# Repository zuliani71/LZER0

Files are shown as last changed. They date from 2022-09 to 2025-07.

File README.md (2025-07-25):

# LZER0


LZER0: a cost-effective multi-purpose GNSS platform (Hardware and Software) developed by OGS for surveying measurements and for monitoring tasks.

## 🔍 Overview
- 📇 Based on u‑blox GNSS receivers (M8T and ZED F9P) + Raspberry Pi Zero W.
- 🧰 Processes data with RTKLIB (real-time RTK/PPK).
- 🖥️ Includes Bash scripts, Ansible provisioning, and web interface for fleet management

## 🚀 Getting Started

To fully utilize an LZER0 device, you will need to set up the hardware, deploy and configure the device's operating system and software, and optionally integrate it into a centralized management system.

### Choose Your Path
- 🔧 **I want to build the hardware** → Continue to the [Hardware Guide](#%EF%B8%8F-hardware-guide) section below
- 💻 **I want to deploy and configure devices** → Go to the [LZER0 Deployment and Provisioning](https://hub.geosciences.cloud/git/geosciencesir-devop/ogs_dev/lzer0_provisioning) repository
- 🌐 **I want to set up the web-based centralized management and configuration system** → Check out the [GNSS-Central-Config](https://hub.geosciences-ir.it/git/geosciencesir-devop/ogs_dev/gnss-central-config) system
- 🛠️ **I want to use command-line tools to interact with LZER0 devices** → Explore the [lzeroutils repository](https://github.com/shakelab/lzeroutils)
- 📚 **I want to understand the complete system** → Continue reading this guide and explore the [research publications](#-articles-and-informations-available-at)

### LZER0 Deployment and Provisioning
The LZER0 Deployment and Provisioning repository is crucial for bringing new Raspberry Pi units to an operative state, allowing them to join a pool of already deployed boards. This process involves a combination of ad-hoc OS image building using pi-gen and IT automation with Ansible.

**Key Stages:**
- **Image Building Stage:** Utilizes pi-gen to create a Raspberry Pi OS Lite image, which is then written to the SD cards of the RPis. This stage includes custom scripts (90-crspi) for installing extra packages, disabling unneeded hardware/services, setting up NetworkManager, and populating a custom.toml file for first-boot scripts.

  - **Customization:** Before the first boot, you can apply board-specific customizations to the SD card, such as setting a custom hostname and providing client-specific VPN configurations.

- **Provisioning Stage:** Uses Ansible playbooks to define and run tasks on all hosts in the inventory.

  - **Inventory Population:** The Ansible inventory can be populated manually or dynamically using Avahi for discovery of IP addresses and hostnames.

  - **Playbooks:** A comprehensive set of Ansible playbooks (main.yaml) is provided for tasks like disabling requiretty, configuring fstab, installing/updating apt packages, managing user groups and SSH keys, setting up NTP, configuring the ufw firewall, establishing persistent VPN connections, syncing root and home directories, installing Python packages with pip, deploying RTKLIB, setting up the GNSS module web interface, configuring PiJuice, and managing crontab entries.

For detailed instructions, please refer to the `README.md` in the [LZER0 Deployment and Provisioning](https://hub.geosciences.cloud/git/geosciencesir-devop/ogs_dev/lzer0_provisioning) repository.

### GNSS-Central-Config

The [GNSS-Central-Config](https://hub.geosciences-ir.it/git/geosciencesir-devop/ogs_dev/gnss-central-config) system enables centralized management of a pool of LZER0 receivers. This system facilitates defining and distributing device configurations, monitoring their status, updating parameters, and coordinating the behavior of the entire GNSS network. This is particularly useful for fleet management, allowing programmatic updates to keep configuration files in sync across all deployed boards.

In addition to the central system, each receiver also hosts a local web-based configuration interface. This configurator plays a crucial role, as it allows the setup of key parameters specific to each device — such as site name, caster credentials, approximate coordinates, and more. While the central system ensures coordination and consistency, the local interface ensures that each receiver can be individually tailored to its deployment context.

## 📦 Components

<table>
  <thead>
    <tr>
      <th style="width: 200px;">Repo</th>
      <th>Description</th>
    </tr>
  </thead>
  <tbody>
    <tr>
      <td colspan="2"><strong>🧰 Software</strong></td>
    </tr>
    <tr>
      <td><a href="https://github.com/OGS-GNSS/homebin_lzer0">homebin_lzer0</a></td>
      <td>Contains scripts, tools, and utility software necessary for the daily operation of the LZER0 receiver. It includes tools for starting services, managing GNSS files, communicating with peripherals, and other system operations. It is the central component that defines the behavior of the device once it is powered on.</td>
    </tr>
    <tr>
      <td><a href="https://github.com/OGS-GNSS/homecfg_lzer0">homecfg_lzer0</a></td>
      <td>Contains examples of the configuration file related to the operation of the LZER0 receiver. Some files are used directly, others are dynamically regenerated at provisioning or boot time.</td>
    </tr>
    <tr>
      <td colspan="2"><strong>🌐 Web-based configuration system</strong></td>
    </tr>
    <tr>
      <td><a href="https://hub.geosciences-ir.it/git/geosciencesir-devop/ogs_dev/gnss-central-config">GNSS-Central-Config</a> (soon public)</td>
      <td>Web interface for centralized management of a pool of LZER0 receivers. It allows you to define and distribute device configurations, monitor their status, update parameters, and coordinate the behavior of the entire GNSS network.</td>
    </tr>
    <tr>
      <td colspan="2"><strong>⚙️ Deployment system</strong></td>
    </tr>
    <tr>
      <td><a href="https://hub.geosciences.cloud/git/geosciencesir-devop/ogs_dev/lzer0_provisioning">LZER0 Deployment and Provisioning</a> (soon public)</td>
      <td>Main repository for the automatic deployment and provisioning of lzer0 devices. It manages the entire device lifecycle: from initial power-up to final configuration. Includes scripts for installation, cloning of the required repositories, and network and service setup.</td>
    </tr>
    <tr>
      <td><a href="https://github.com/OGS-GNSS/lzer0_generic_assets">Assets to be configured</a></td>
      <td>Contains the customizable assets needed to adapt the provisioning system to your operating environment. This repository is automatically cloned by the provisioning system.</td>
    </tr>
     <tr>
      <td colspan="2"><strong>🛠️ Client-Server tools </strong></td>
       <tr>
        <td><a href="https://github.com/shakelab/lzeroutils">lzeroutils</a></td>
        <td>Supplementary command-line tools and utilities to interact with LZER0 devices. Useful for debugging, automation, and data extraction. Can be used independently or integrated with the core system.</td>
      </tr>
    </tr>
  </tbody>
</table>

## 🛠️ Hardware Guide

This repository contains all the hardware designs, schematics, and documentation needed to build LZER0 devices.

### What You'll Find Here

#### Core Hardware Designs
- **PCB schematics** - Complete electrical designs for LZER0 boards
- **PCB layouts** - Ready-to-manufacture Gerber files
- **Bill of Materials (BOM)** - Component lists with part numbers
- **Assembly instructions** - Step-by-step hardware assembly guides
- **Mechanical drawings** - Enclosure and mounting specifications

#### Key Components
- **u-blox GNSS receiver module (M8T and ZED F9P)** - Professional-grade timing receiver
- **Raspberry Pi Zero W** - ARM-based computing platform with WiFi
- **Custom interface PCB** - Connects GNSS receiver to Raspberry Pi
- **Power management** - Efficient power supply and distribution
- **I/O interfaces** - GPIO, serial, and expansion connectors

#### Important Note
The original LZER0 hardware was developed using the u-blox M8T receiver. However, this repository also includes designs for the LCC variant, based on the u-blox ZED-F9P, which supports multi-band GNSS and offers enhanced precision and performance.

### Manufacturing Your LZER0

1. **Download design files** from the `/hardware/` directory
2. **Source components** using the provided BOM
3. **Manufacture PCBs** using the Gerber files with your preferred fabricator
4. **Assemble hardware** following the assembly guide
5. **Test hardware** before software installation

### Hardware Variants

LZER0 supports multiple hardware configurations:

#### LZER0-MONI 
Intended for permanent monitoring applications such as landslide or infrastructure observation. The unit is typically installed inside a solar-powered pillar with a panel, charge controller, and backup battery. It features the u-blox M8T receiver and 

Raspberry Pi connected via USB, and includes a built-in web server with real-time data visualization (e.g., NS/EW/UP displacements and interactive map).

#### LZER0-TOPO
A compact version designed for topographic and cadastral surveying. It uses a u-blox M8T GNSS receiver and a rechargeable LiPo battery, all housed in a 3D-printed enclosure with an integrated TW4721 antenna on a metallic support. The device connects wirelessly to an Android tablet, enabling real-time tracking of survey points and trajectories in the field.

#### LZER0-AUTO
Developed for automotive and dynamic positioning applications, such as agricultural machinery. The electronics (u-blox M8T, Raspberry Pi Zero W, and ATXraspi interface board) are enclosed in a rugged industrial-grade Gewiss GW44427 box. Powered by the vehicle's battery (24V to 5V converter), it connects to a tablet in the cabin, which provides NTRIP corrections and real-time guidance

#### LZER0-MOB (documentation will be uploaded)
LZER0-MOB is a standalone GNSS device designed for temporary measurement campaigns and mobile deployments. It integrates a GNSS receiver (u-blox ZED-F9P), a Raspberry Pi, and an internal modem for remote connectivity.
It can be powered by external batteries or solar panels, making it fully autonomous and ideal for rapid field deployment.

Developed within the Geosciences IR project, it uses the LZER0 Core Card (LCC) ver. 2021, based on the u-blox ZED-F9 chipset.

#### LZER0-NET (documentation will be uploaded)
LZER0-NET is built for reliable, continuous GNSS monitoring, especially in remote or critical installations. It includes a mini-UPS based on the PiJuice board, enabling power backup, safe shutdowns, and automatic recovery.

It combines the u-blox ZED-F9 GNSS receiver with a Raspberry Pi and supports real-time data streaming and web-based monitoring.
It features the LZER0 Core Card (LCC) ver. 2022, based on the same ZED-F9 chipset, with improved hardware integration.

## ✨Acknowledgments
The development of LZER0 has been supported over the years by several projects and funding sources:
- the development of the LZER0-NET and of the LCC was supported by the agreement between the National Institute of Oceanography and Applied Geophysics - OGS and the Civil Protection of the Friuli Venezia Giulia Region;
- the development of the LZER0-MOB variant, of the GNSS-Central-Config system and of the LZER0 Deployment and Provisioning system was funded by European Union - NextGenerationEU - Mission 4 “Education and Research” - Component 2 “From Research to Business” - Investment 3.1 “Fund for the realization of an integrated system of research and innovation infrastructures” - Project IR0000037 - GeoSciences IR - CUP I53C22000800006;
- LZER0 was tested within the RETURN project as a real-time monitoring device at the Cazzaso landslide, at two test sites on a building of the University of Naples, and at two sites along the Rome–Naples railway line. As part of the RETURN project, and in collaboration with Sapienza University of Rome, we are also carrying out a technology transfer initiative aimed at increasing the Technology Readiness Level (TRL) of the LZER0 system.

LZER0 software integrates software developed in the following third-party projects:
- [RTKLIB](https://github.com/rtklibexplorer/RTKLIB)
- [Ansible](https://www.ansible.com/)
- [Pi-Gen](https://github.com/RPi-Distro/pi-gen)

## 📄 Articles and informations available at:
- https://doi.org/10.3390/s22218314<br>
- https://doi.org/10.5194/egusphere-egu2020-9506<br>
- http://dx.doi.org/10.13140/RG.2.2.22750.05447<br>
- http://dx.doi.org/10.13140/RG.2.2.32319.61605<br>
- https://doi.org/10.3390/s22010350<br>
- https://hdl.handle.net/20.500.14083/43383<br>

## 📄 License

This project is licensed under the [Creative Commons Attribution 4.0 International (CC BY 4.0)](https://creativecommons.org/licenses/by/4.0/) license.



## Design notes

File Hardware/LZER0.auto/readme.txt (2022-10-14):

This version needs:
a) a rasperry pi zero W
b) an ATXRaspi board available at: https://lowpowerlab.com/guide/atxraspi/
c) an u-blox M8T USB board (see the pdf schematic here included)

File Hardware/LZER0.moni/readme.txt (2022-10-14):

This version needs:
a) a rasperry pi zero W
b) an external power supply system (e.g. solar pannels and batteries)
c) an external data transmission system (e.g. LAN ethernet)
d) an u-blox M8T USB board (see the pdf schematic included in Hardware/LZER0.auto)

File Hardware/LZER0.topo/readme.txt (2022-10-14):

a) a rasperry pi zero W
b) an u-blox M8T OGS board (see the schematic_eagle_4_16 dir)
c) an optional enclosure (see the 3D_sketchup dir)

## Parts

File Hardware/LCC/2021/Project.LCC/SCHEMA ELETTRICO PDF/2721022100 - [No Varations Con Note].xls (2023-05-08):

 | Component list |  |  |  | LZER0 Core Card
 | Project: |  |  |  | 2721022100
 | Variant: |  |  |  | 1.4 [no variant (completa)]
 | Report Date: |  |  | 18/08/2022 | 18:24
 | Print Date: |  |  | 2022-08-23 | 17:52:29
# | Designator | Comment | Case | Manufacturer n | Order c | Description |  |  | Quantity
1 | B1 | 3V |  | MS621FE-FL11E | 628-MS621FE-FL11E | Recharge Battery/Tab RTC/SRAM Backup |  | 0 | 1
2 | C1, C3, C5, C6, C7, C9, C10, C13 | 10uF | 603 | GRM188R61A106ME69D | 81-GRM188R61A106ME9D | CAP, MLCC, X5R, 10UF, 10V, X5R, 0603 | 0.03 | 0.24 | 8
3 | C2, C4, C11 | 100nF | 402 | GRM155R71C104KA88D | 8819742 | CAP, CERAMICA, 100NF, 16V, X7R, 0402 | 0.01 | 0.03 | 3
4 | C8 | 100nF | 603 | GRM188R71H104KA93 | 81-GRM188R71H104KA93 | CAP, CERAMICA, 100NF, 50V, X7R, 10%, -55+125C°, 0603 | 0.0018 | 0.0018 | 1
5 | C12 | 47pF | 402 | GJM1555C1H470FB01D | 81-GJM1555C1H470FB1D | CAP, CERAMICA, 47pF, 50V, C0G, 1%, 0402 | 0.01 | 0.01 | 1
6 | D1 | BAS70-06W,115 | SOT323 | BAS70-06W,115 | 771-BAS70-06W-T/R | DIODO DOPPIO SCHOTTKY, 70V, 0.15A, SOT323(SC70) |  | 0 | 1 | NOTA 1
7 | D2 | Y | SMD | APT1608SYCK | 604-APT1608SYCK | LED, 0603, YELLOW, 150MCD, 590NM | 0.047 | 0.047 | 1
8 | D3 | B | SMD | APT1608VBC/D | 604-APT1608VBC/D | LED, 0603, BLUE, 180MCD, 470NM | 0.141 | 0.141 | 1
9 | D4, D6 | G | SMD | 150060VS55040 |  | LED, 0603, GREEN, 15MCD, 675NM | 0.1 | 0.2 | 2
10 | D5 | R | 603 | KPT-1608EC | 2099221 | LED, 0603, RED, 15MCD, 625NM |  | 0 | 1
11 | D8, D10 | 3A 10V | SOD-323 | BAT60JFILM | 1467544 | DIODO, SCHOTTKY, 3A, 10V, SMD |  | 0 | 2
12 | D9 | RED | 603 | KPT-1608EC | 2099221 | LED, 0603, RED, 15MCD, 625NM |  | 0 | 1
13 | J1, J2 | DF13-10P-1.25H |  | DF13-10P-1.25V(76) | 798-DF13-10P-1.25V76 | CONNECTOR 10P SNG ROW PIN HDR R/A SMT | 0.6 | 1.2 | 2
14 | J3, J6, J8, J14 | CON2P |  | 825433-2 | 3417645 | HEADER, P2.54, H6.7MM, BIFASE |  | 0 | 4
15 | J4, J5, J7 | 3P |  | SPC20479. | 2396301 | JUMPER P2.54, H13.5MM, FEMMINA 2 VIE | 0.075 | 0.225 | 3
16 | J9 | USB C |  | USB4105-GF-A-120 | 640-USB4105-GF-A-120 | MICRO USB TYPE C, SMT Horizontal | 0.389 | 0.389 | 1
17 | J10, J13 | CON5P |  | 61300515721 | 2827892 | Connettore, PCB, 2.5MM, 5 VIE, 12 AMPER | 0.753 | 1.506 | 2
18 | J12 | 2P |  | 691103110002 | 1841248 | MORSETTIERA, PCB, 3.5MM, 2 VIE, 16 AMPER | 0.46 | 0.46 | 1 | NOTA 2
19 | J12A | 2P |  | S2B-PH-SM4-TB(LF)(SN) | 455-1749-1-ND | Connector Header, PH Series, 2 Position, Side Entry, 2.00mm, Solder, Surface Mount |  | 0 | 1 | NOTA 2
20 | L1, L2 | BLM 2A | 603 | BLM18EG101TN1D | 81-BLM18EG101TN1D | FERRITE, BEAD, 0603, 100OHM, 2A | 0.064 | 0.128 | 2
21 | L3 | 120nH 0.3A | SMD | LQW18ASR12J0CD | 81-LQW18ASR12J0CD | INDUCTOR, RF, 120nH, 0.3A, 5%,1.3GHZ | 0.183 | 0.183 | 1
22 | LC1 | TBD | 402 | TBD | TBD | R/L/C TBD, 1%, 0402, SMD | 0.0006 | 0 | 0 | NOTA 3
23 | M1 | PCB MODULO BL |  |  |  | Generic Antenna |  | 0 | 1 | NOTA 4
24 | Q1 | BCX17,215 | SOT23 | BCX17,215 | 771-BCX17-T/R | TRANSISTOR, NPN 50V, -500mA, SOT-23 | 0.042 | 0.042 | 1
25 | Q2 | BC857C-7-F | SOT23 | BC857C-7-F | 621-BC857C-7-F | TRANSISTOR, NPN 50V, -200mA, SOT-23 | 0.025 | 0.025 | 1
26 | Q3 | ADTC114YUAQ |  | ADTC114YUAQ-7 | 621-ADTC114YUAQ-7 | DIGITAL TRANSISTOR, 10K-47K, NPN, 50V, SC-75-3 | 0.042 | 0.042 | 1
27 | R1, R2, R3, R12, R14, R16, R18 | 1K | 603 | CRCW06031K00FKEA | 1469740 | RESISTORE, 1K, 0.1W, 1%, 0603, SMD | 0.00066 | 0.00462 | 7
28 | R4, R5, R6, R8, R9, R10, R11, R13, R15, R17, R19, R20, R29 | 100R | 603 | CRCW0603100RFKEA | 1469752 | RESISTORE, 100R, 0.1W, 1%, 0603, SMD | 0.00066 | 0.00858 | 13
29 | R7, R31, R32, R33, R35 | 0R | 402 | CRCW04020000Z0ED | 1469661 | RESISTORE, 0R, 0.1W, 1%, 0402, SMD | 0.0006 | 0.003 | 5 | NOTA 5
30 | R21 | 255K | 603 | CRCW0603255KFKEAC | 71-CRCW0603255KFKEAC | RESISTORE, 255K, 0.1W, 1%, 0603, SMD | 0.00066 | 0.00066 | 1 | NOTA 6
31 | R22 | 82K | 603 | CRCW060382K0FKEAC | 71-CRCW060382K0FKEAC | RESISTORE, 82K, 0.1W, 1%, 0603, SMD | 0.00066 | 0.00066 | 1 | NOTA 6
32 | R23 | 1R | 805 | CRCW08051R00FKEAHP | 71-CRCW08051R00FKEAH | RESISTORE, 1R, 0.5W, 1%, 0805, SMD | 0.046 | 0.046 | 1
33 | R24 | 330R | 603 | CRCW0603330RFKEA | 71-CRCW0603-330-E3 | RESISTORE, 330R, 0.1W, 1%, 0603, SMD |  | 0 | 1
34 | R25 | 2k7 | 603 | CRCW06032K70FKEAC | 71-CRCW06032K70FKEAC | RESISTORE, 2.7K, 0.1W, 1%, 0603, SMD | 0.00066 | 0.00066 | 1
35 | R26, R27, R41 | 0R | 603 | CRCW06030000Z0EA | 1469739 | RESISTORE, 0R, 0.1W, 1%, 0603, SMD | 0.00066 | 0.00198 | 3 | NOTA 7/8
36 | R28, R43 | 10K | 603 | CRCW060310K0FKEA | 1469748 | RESISTORE, 10K, 0.1W, 1%, 0603, SMD | 0.00066 | 0.00132 | 2 | NOTA 9
37 | R30 | 560R | 603 | CRCW0603560RFKEA | 71-CRCW0603-560-E3 | RESISTORE, 560R, 0.1W, 1%, 0603, SMD | 0.00066 | 0.00066 | 1
38 | R36, R37 | 27R | 402 | CRCW040227R0JNED | 3546346 | RESISTORE, 27R, 0.063W, 5%, 0402, SMD |  | 0 | 2
39 | R38 | 100K | 603 | CRCW0603100KFKEA | 1469649 | RESISTORE, 100K, 0.1W, 1%, 0603, SMD | 0.00066 | 0.00066 | 1
40 | R39, R40 | 5k1 | 603 | CRCW06035K10FKEB | 71-CRCW06035K10FKEB | RESISTORE, 5K1, 0.1W, 1%, 0603, SMD | 0.00066 | 0.00132 | 2
41 | R42 | 510R | 603 | CRCW0603510RFKEA | 1469826 | RESISTORE, 510R, 0.1W, 1%, 0603, SMD |  | 0 | 1
42 | U1 | ZED-F9P | SMD |  |  | u-blox F9 high precision GNSS module | 169 | 169 | 1
43 | U2 | NCV8705ML33TCG | SMD | NCV8705ML33TCG | 3368462 | IC, V REG, LDO 2.5-5.5 Vin,3.3V, DFNW8, 500mA | 0.529 | 0.529 | 1
44 | U4 | SN74LVC2G14DCKT | SC70-6 | SN74LVC2G14DCKT | 595-SN74LVC2G14DCKT | Dual Schmitt Trigger Inverter, SC70-6 | 0.65 | 0.65 | 1
45 | U6 | MCP73831 | SOT-23-5 | MCP73831T-2ACI/OT | 579-MCP73831T-2ACIOT | Miniature Single-Cell, Fully Integrated Li-Ion, Li-Polymer Charge Management Controllers |  | 0 | 1
46 | Y1 | JACK MCX | SMD | 60612202111308 | 732-14177-1-ND | WR-MCX MCX PCB End Launch Jack | 2.8 | 2.8 | 1
47 | Y2 | UFL | SMD | U.FL-R-SMT(10) | 798-U.FL-R-SMT10 | U.FL | 0.59 | 0.59 | 1 | NOTA 10
48 | Z1, Z3, Z4 | 14V | SMD | PESD0402-140 | 650-PESD0402-140 | TVS Diodes - 0.25pF, 12V, 3.4Ghz |  | 0 | 3
49 | Z2 | 18V | SMD | CG0402MLE-18G | 2846102 | TVS Diodes - 9pF, 18V |  | 0 | 1
Approved |  |  |  |  | Notes |  | Total E. | 178.50892 | 97
 |  |  |  |  | NOTA1: nel PCB e' previsto il footpint SOT23 al posto del footprint SC70, o si monta il BAS70-06 o si cambia il footprint
 |  |  |  |  | NOTA2: montare J12 o J12A in base all'esigenze
 |  |  |  |  | NOTA3: non montare LC1, predisposizione per il tuning
 |  |  |  |  | NOTA4: montare in base all'esigenze
 |  |  |  |  | NOTA5: montare R35 per escludere il limitatore di corrente, vedere lo schema
 |  |  |  |  | NOTA6: non montare predisposizione per versione ADJ di U2
 |  |  |  |  | NOTA7: attenzione! Non montare entrambe le resistenze R26 R27 altrimenti si mette in corto I 3,3v con I 5v e lo ZED si danneggia
 |  |  |  |  | NOTA8: montare R41 in base l'esigenze, vedere lo schema
 |  |  |  |  | NOTA9: cambiando il valore di R43 si modifica il valore della corrente di ricarica, nel campione e' stato scelto un valore uguale a 3,3K ohm vedere email del 19/5/22
 |  |  |  |  | NOTA10: nel campione e' stato montato il pn WURTH 63610111001

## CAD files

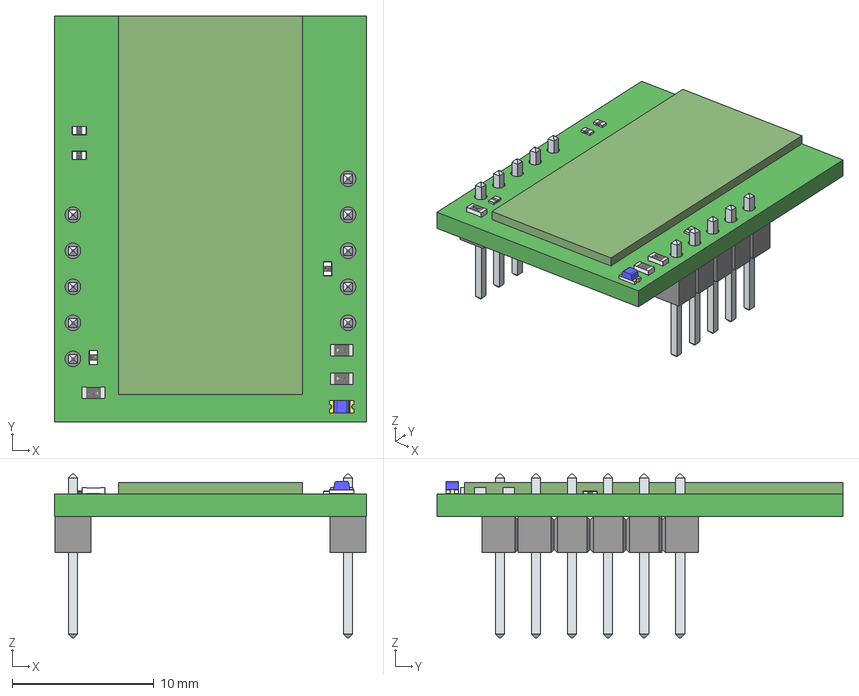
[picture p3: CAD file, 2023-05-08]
Hardware/LCC/2021/Project.BT.module/BOARD 3D FORMATO STEP + DXF BOARD/ExportSTEP/BLE.step
22.0 x 28.6 x 11.5 mm
User_Library-Panasonic0603 x 3
Extruded
User_Library-LTST-C190TBKT_Pad
User_Library-LTST-C190TBKT_Pad005
User_Library-LTST-C190TBKT_Pad001
User_Library-LTST-C190TBKT_Pad004
User_Library-LTST-C190TBKT_Pad003
User_Library-LTST-C190TBKT_Lens
User_Library-0402_SMD_Resistor x 4
LeadsArray x 2

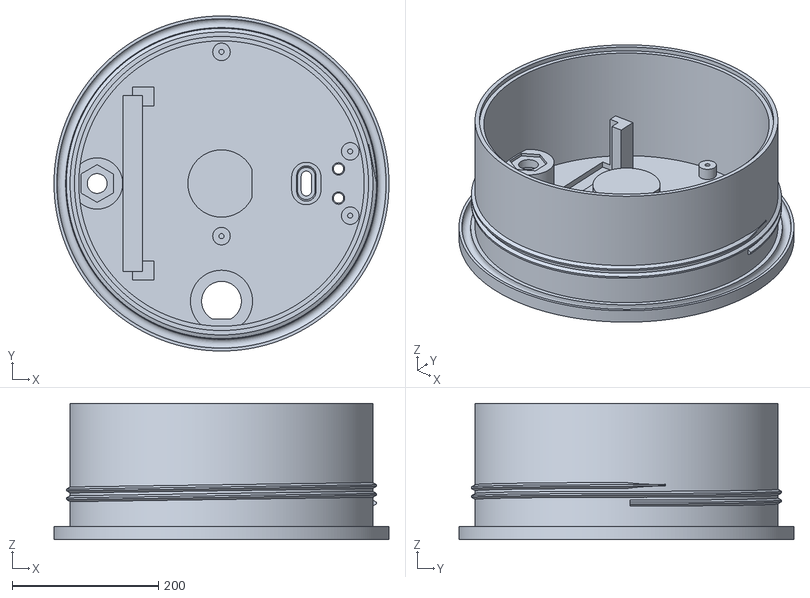
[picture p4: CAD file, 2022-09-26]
Hardware/LZER0.topo/3D_sketchup/STL/case_2018_03_28/scatola_5_0_o.stl
458.0 x 458.0 x 186.0

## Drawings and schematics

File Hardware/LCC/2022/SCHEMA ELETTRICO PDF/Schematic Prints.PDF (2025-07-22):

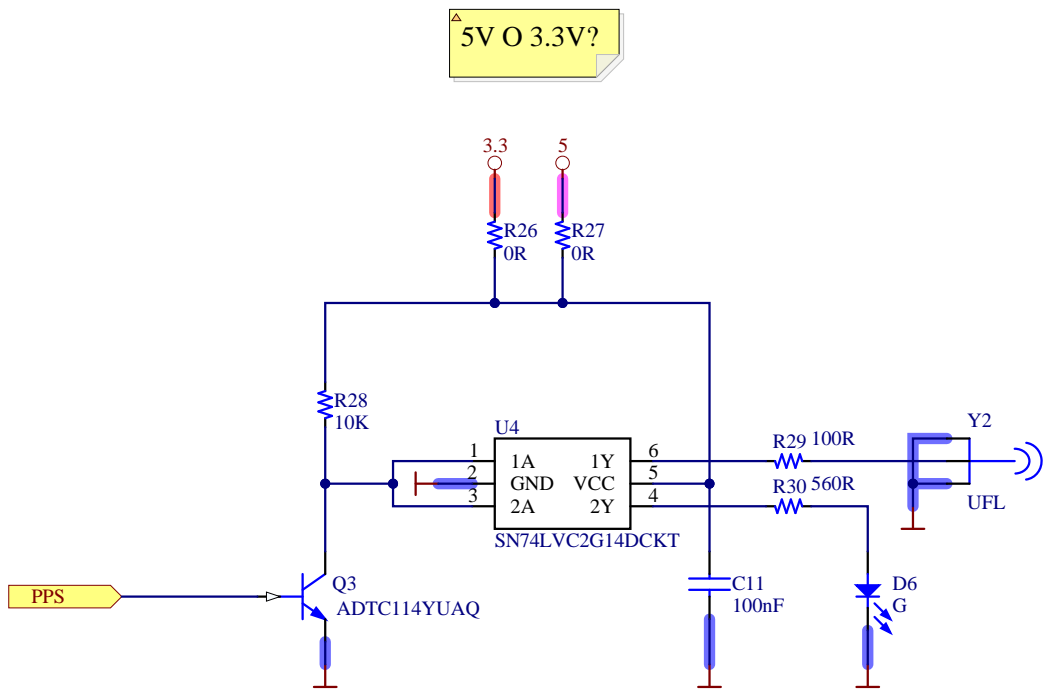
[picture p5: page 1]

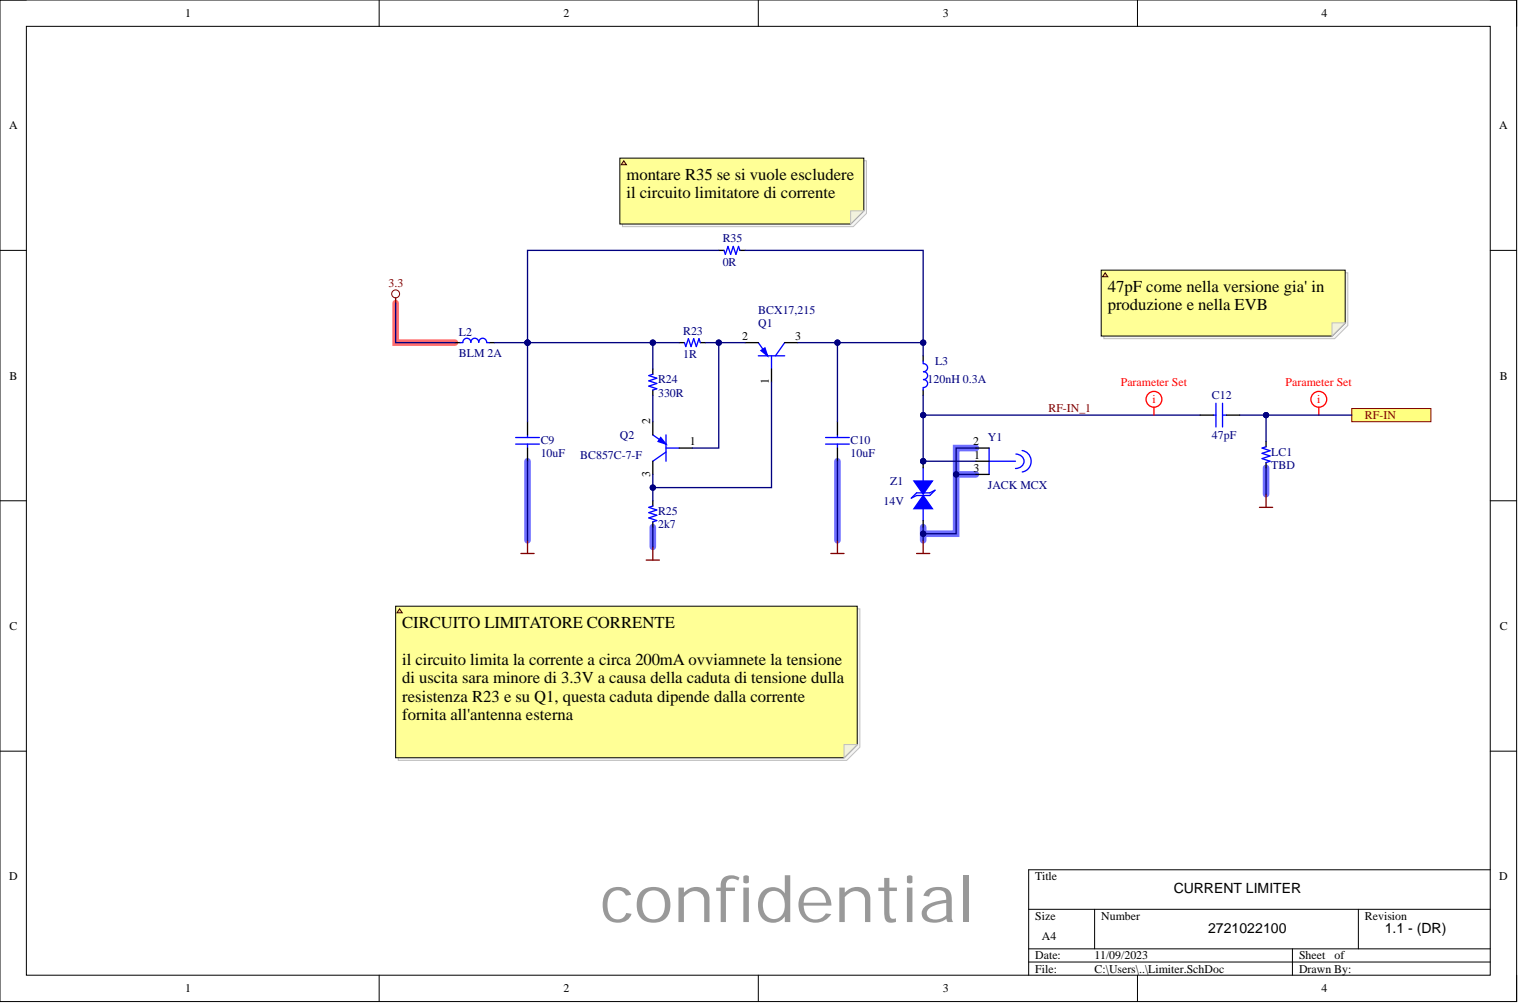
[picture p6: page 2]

montare R35 se si vuole escludere
il circuito limitatore di corrente

47pF come nella versione gia' in
produzione e nella EVB

il circuito limita la corrente a circa 200mA ovviamnete la tensione
di uscita sara minore di 3.3V a causa della caduta di tensione dulla
resistenza R23 e su Q1, questa caduta dipende dalla corrente
fornita all'antenna esterna

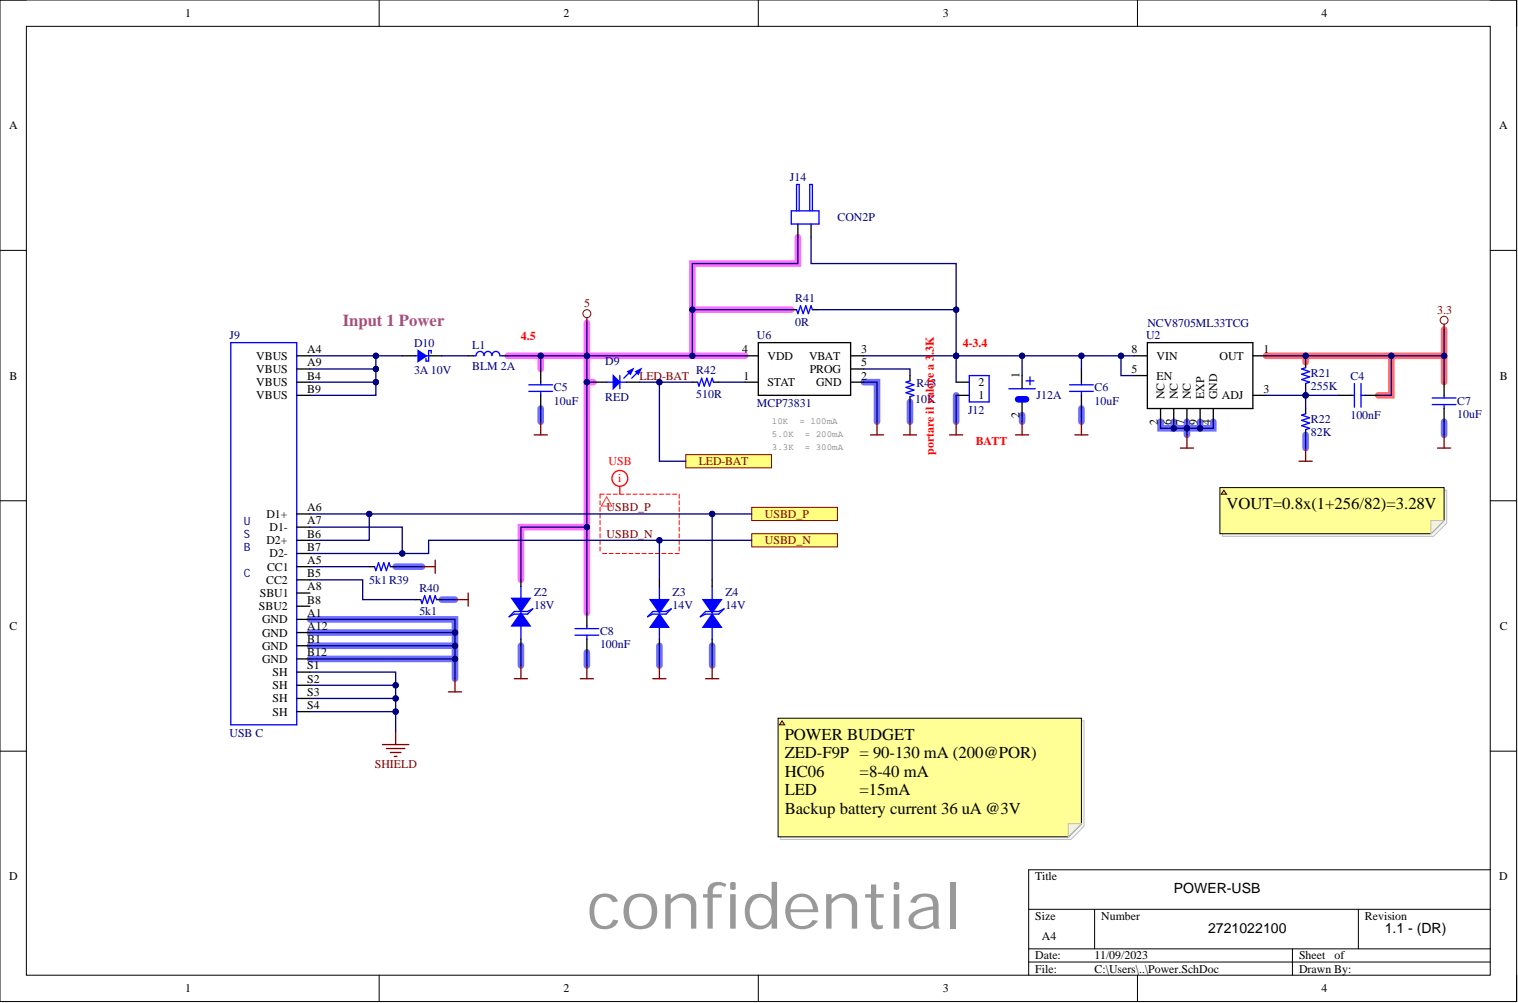
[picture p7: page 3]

POWER BUDGET
ZED-F9P = 90-130 mA (200@POR)
Backup battery current 36 uA @3V

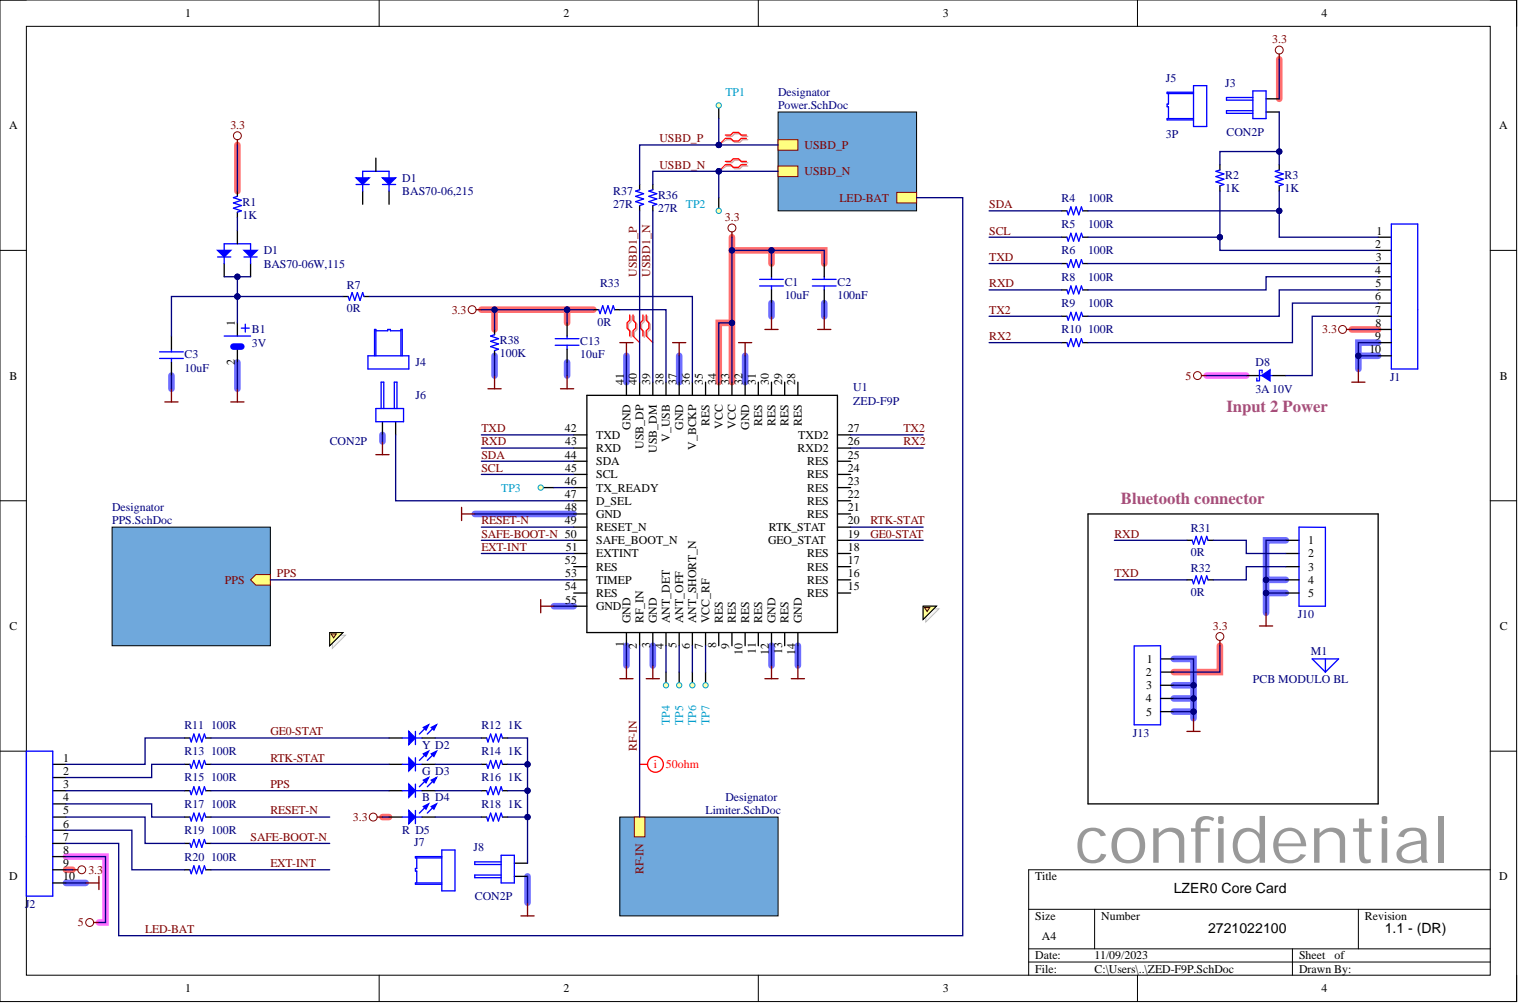
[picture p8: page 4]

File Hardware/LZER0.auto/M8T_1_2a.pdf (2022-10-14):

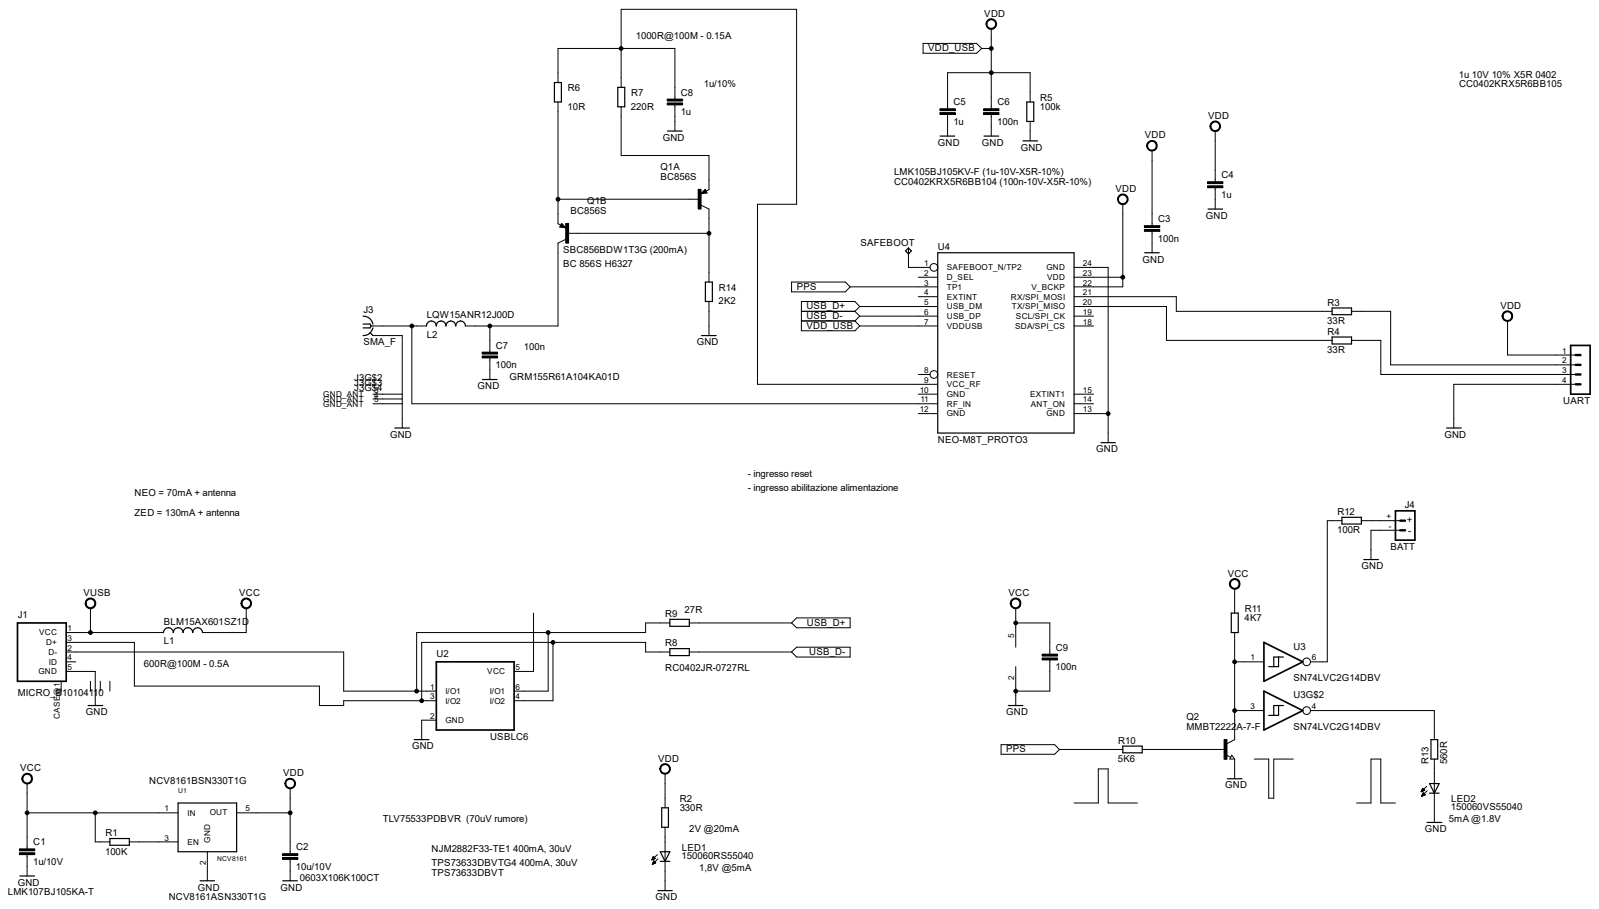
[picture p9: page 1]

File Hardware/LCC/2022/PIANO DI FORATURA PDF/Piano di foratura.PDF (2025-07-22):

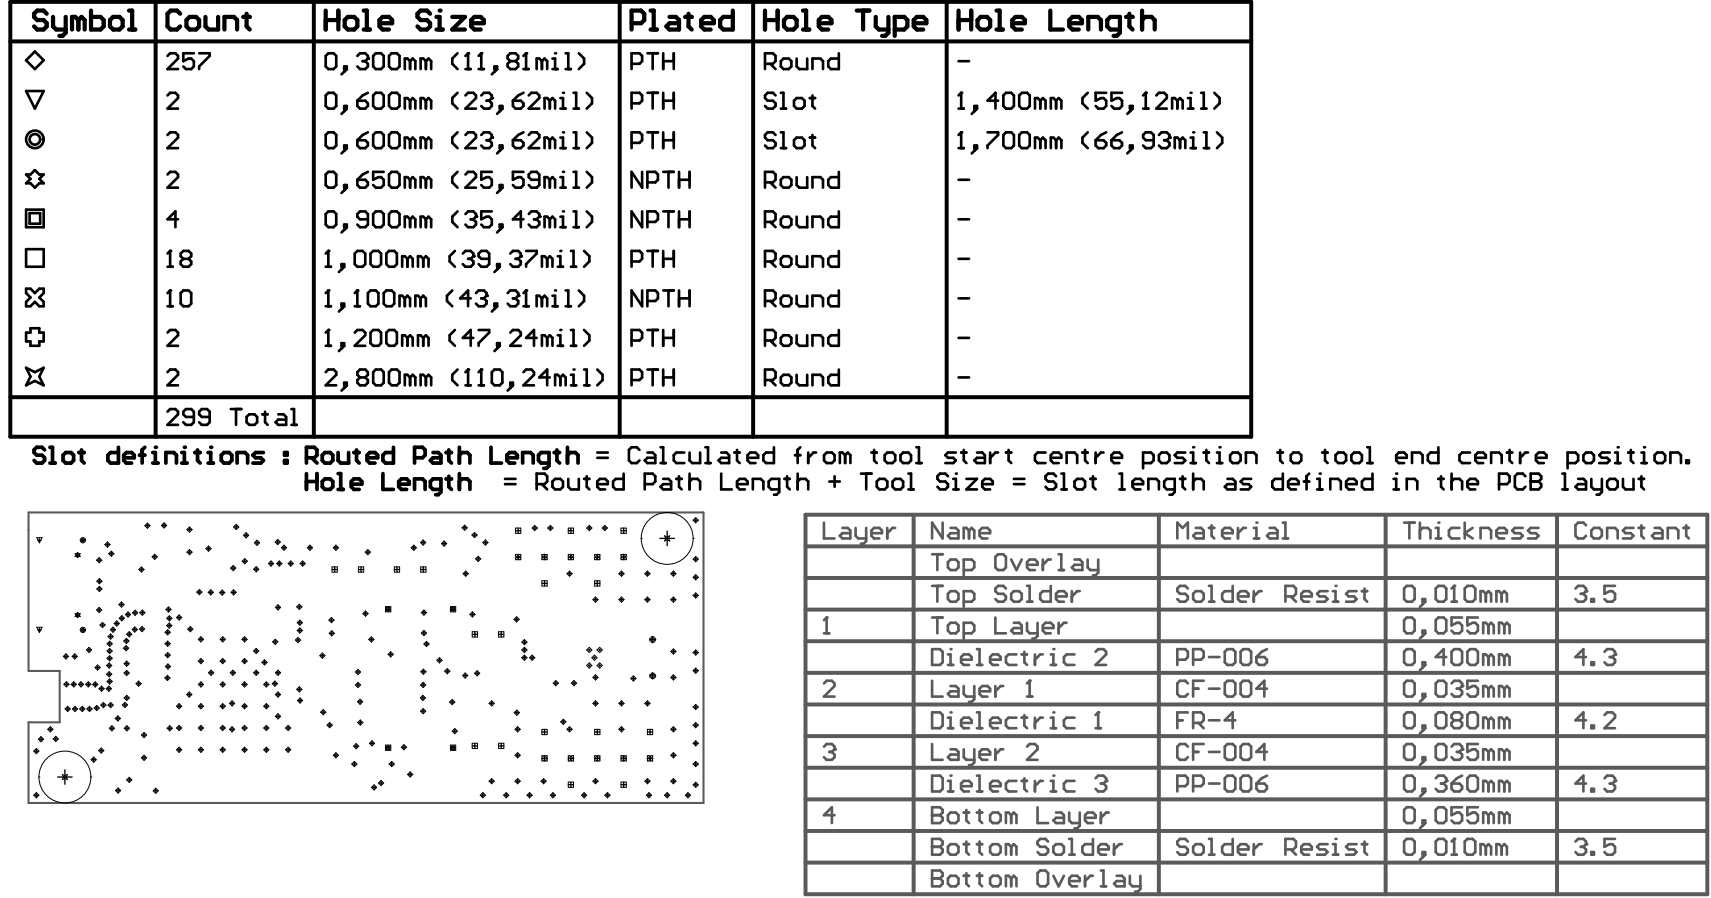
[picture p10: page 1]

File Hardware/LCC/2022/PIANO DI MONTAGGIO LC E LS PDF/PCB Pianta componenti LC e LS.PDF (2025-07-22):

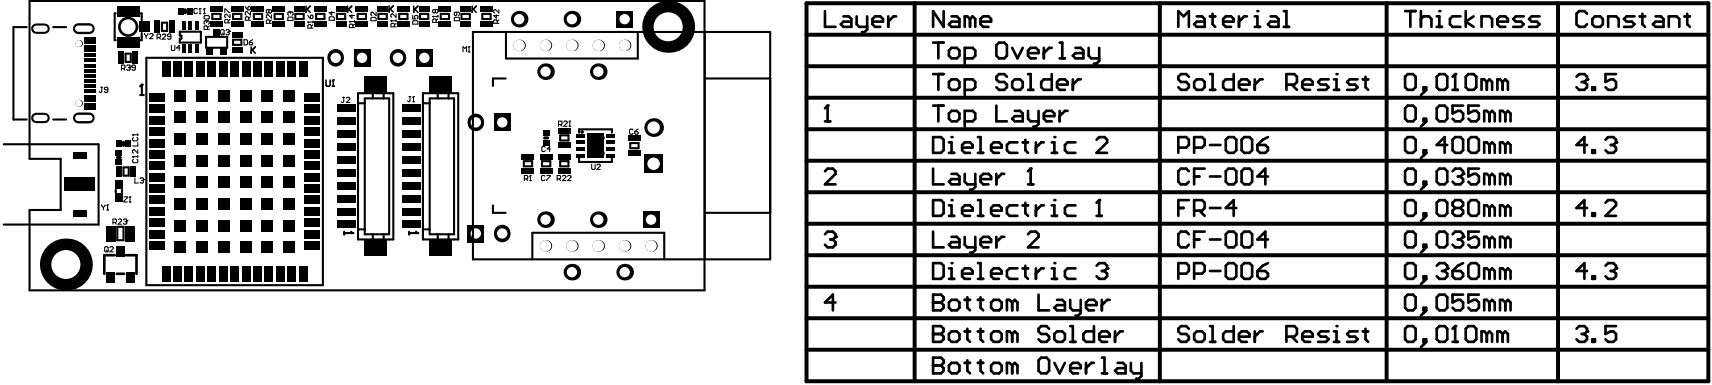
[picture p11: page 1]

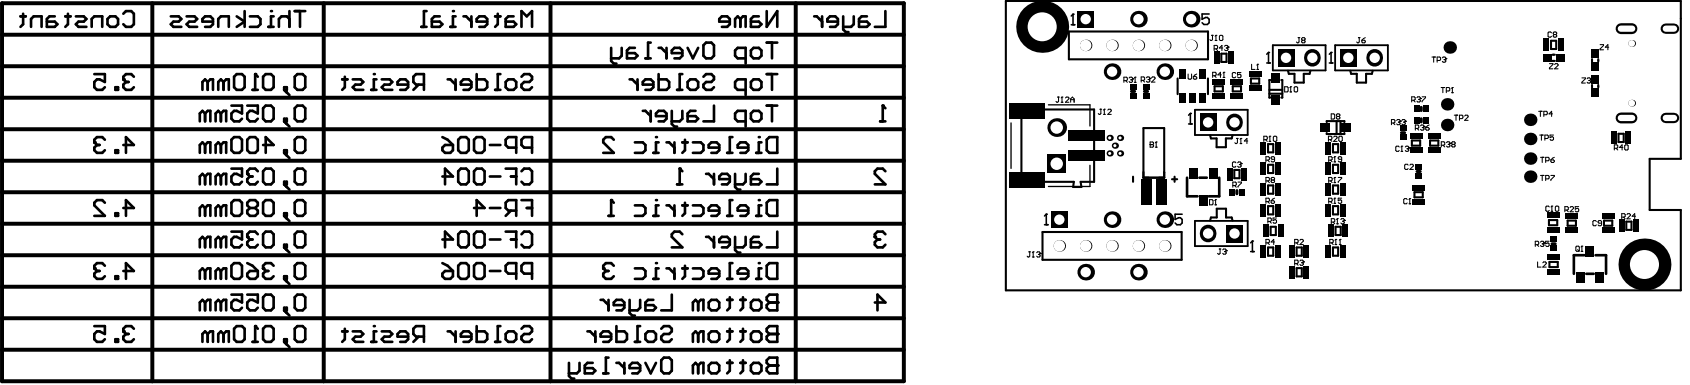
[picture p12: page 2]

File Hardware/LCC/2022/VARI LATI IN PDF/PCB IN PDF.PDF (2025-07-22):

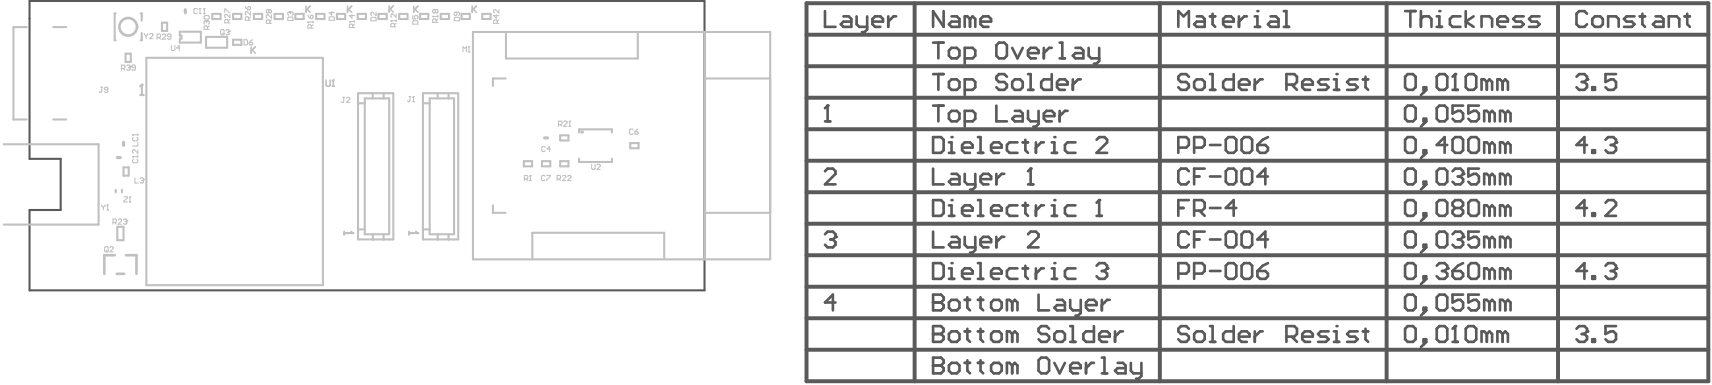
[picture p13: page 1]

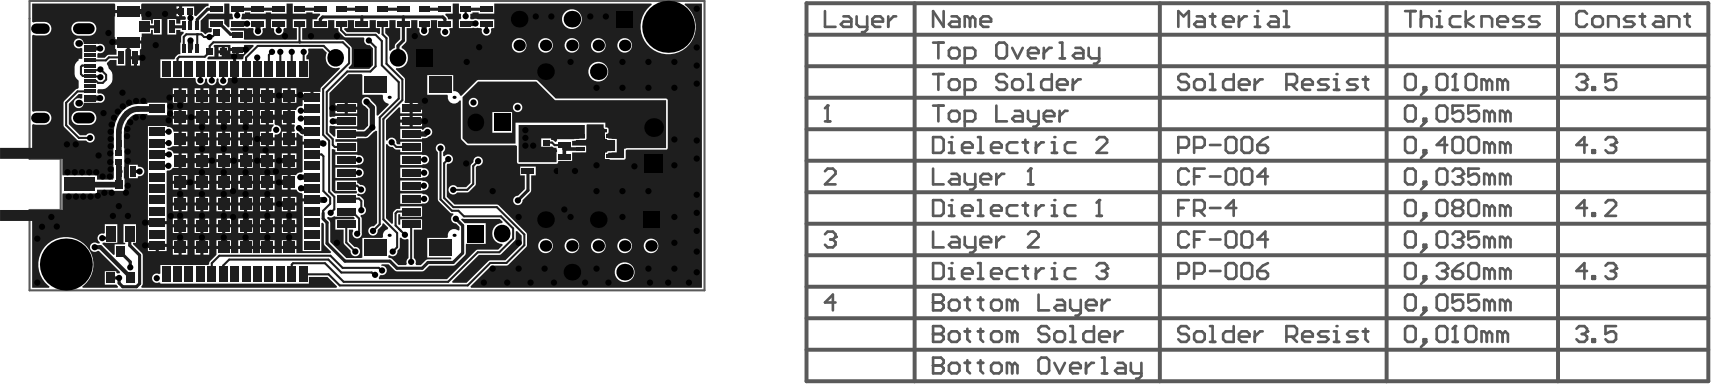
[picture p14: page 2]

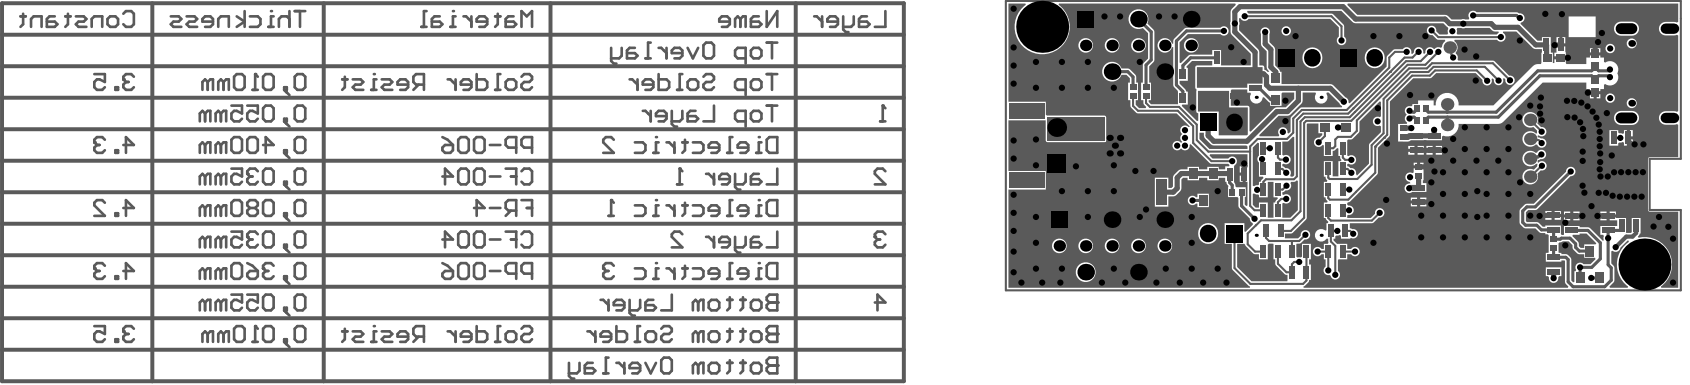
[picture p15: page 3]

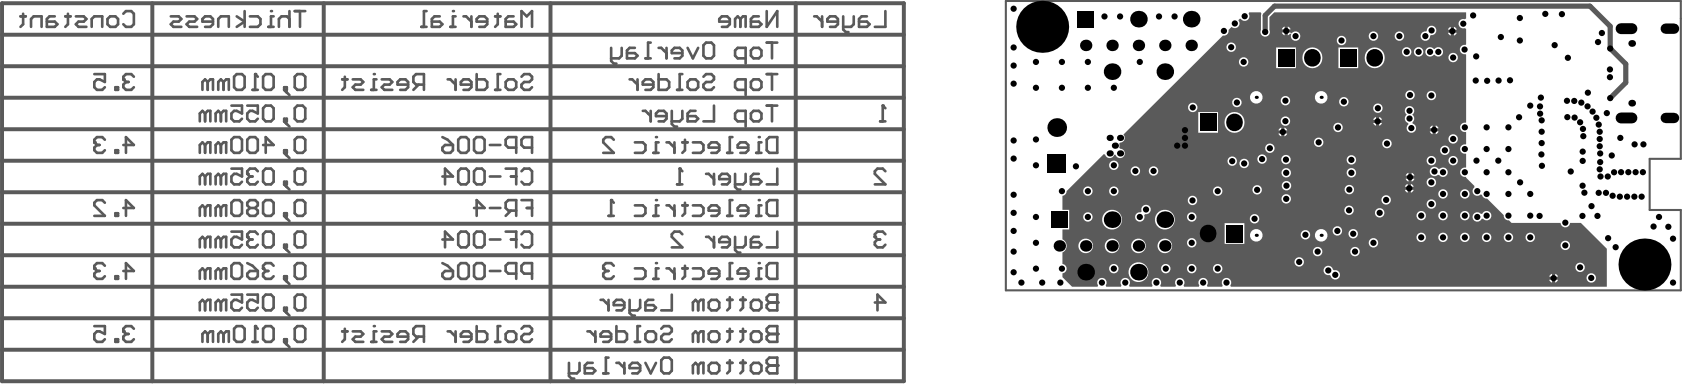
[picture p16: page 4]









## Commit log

2022-09-26 aggiunto il file note.txt per fare una prova
2022-09-26 Added informations for the hardware part of LZER0.topo
    [scatola_5_0_o.stl, zero_3_2b4_b.brd, zero_3_2b4_b.sch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]
2023-05-08 Added LZER0 CORE CARD schematics:wq
    [2721022100 - [No Varations Con Note].xls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]
2025-07-22 New directory for LCC 2021 version
    [2721022100 - [No Varations Con Note].xls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]
2025-07-22 Added LCC 2022 Version
    [2721022100.GBL, 2721022100.GBO, 2721022100.GBP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]
